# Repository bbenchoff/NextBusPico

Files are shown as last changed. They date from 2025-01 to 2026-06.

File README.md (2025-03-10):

# Multi-Stop Bus Tracker (and a tide display. and possibly weather.)

The render of the Bus Display

I live in SF, with some of the best public transit in the country. I would like to know when the next bus will be arriving at a stop near my house. Not just one stop, either: there are several bus lines that will all take me downtown, but they're all served by different stops. I need a device that will ping the city's API for _all_ the bus stops near my house, and condense that into a list I can put on a small display somewhere. I don't want to dedicate a whole computer to this task, so I need to build an embedded solution.

The standard MUNI bus display at some bus stops

This is somewhat different than the displays actually found at bus stops around the city (above). By their nature, the displays at one bus stop do not track the arrivals at other nearby bus stops. It can be done, I just need the data. This can be done through the [511.org API](https://511.org/). Given any bus stop in the city, this API will give me predicted times of arrivals each bus scheduled at that stop, its line number/letter, and its destination. There is a rate limit on this API of 60 requests per hour, but that only means I'm sending a request every 65 seconds.

But there are a few problems:

- The 511.org API *only* works with HTTPS. 
- The API *only* gives me gzipped JSON. I need to decompress this on the device.
- I need to do this on an embedded device. I'm using a Pi Pico2W, simply because that's the bullshit I'm currently on.

## Previous work and initial steps

I started this project with just a Raspberry Pi Pico (with Ethernet) simply as a proof of concept that it's possible to pull arrival data in an embedded device. [Some reddit user](https://www.reddit.com/r/sanfrancisco/comments/16x7zi4/made_a_next_muni_timer_with_a_few_other_handy/) built something similar with an ESP-32, but was confounded by the fact that 511.org only works with HTTPS, and the API only returns gzipped JSON. The solution for that project was to build a Node app to download and decompress the data. This is not an ideal solution.

There is [another project that does something like this](https://github.com/mmichon/esp-nextbus-mini/tree/master), using an ESP-8266. This project does not ping the 511.org API directly, but simply downloads data from [nextbus](http://nextbus.com/). Again, the two key problems are not addressed. This uses a second server, and doesn't interact with the 'ground truth' of the actual API data. Also the display on both of the above devices is really small.

The ideal solution should work even if there are only two computers left on the planet -- the 511.org server, and this device. This means solving the problems of getting data over HTTPS and decompressing the JSON file. I should also use a _good_ display for this, because I really hate how small those little I₂C displays are.

To solve these problems, I picked up a Pi Pico board with an Ethernet module tacked on. In my real job I've found this to be a great way to get data off a network, and the Pico should have more than enough RAM to store the decompressed JSON as well as a screenbuffer or two. The Pico with Ethernet board allowed me to move over to a PicoW board in the future, giving me WiFi connectivity. 

## Problem 1: HTTPS and Decompressing JSON

Getting data from the 511.org API presents two immediate challenges: the API requires HTTPS connections, and it only returns gzipped JSON data. This is an unusual requirement for embedded projects; most examples of accessing web APIs on microcontrollers use plain HTTP, and compressed data is rarely seen in embedded applications.

HTTPS was the easier of these problems to solve; the SSLClient library for Arduino handles the SSL/TLS handshake and encryption. The only tricky part was getting the correct SSL certificates in the right format. [A web-based tool](https://openslab-osu.github.io/bearssl-certificate-utility/) creates a trust_anchors.h file containing the certificates needed for SSL verification - you just input the domain name (api.511.org) and it generates the properly formatted certificate array that SSLClient needs. With the correct certificates in place, SSLClient manages the encrypted connection transparently.

Figuring out the payload was another matter entirely. At first, every response I was getting from the server was garbage, even when telling the server to send me *un*compressed JSON. Looking at the hex dump of the data I was receiving told me another story.

The key insight that told me it was gzipped JSON

### I can not tell you how many times looking at a hex dump has saved my ass.

The 0x1F 0x8B is the magic number for gzip encoding. Once I saw that, I knew I needed a library for decompressing gzip on an embedded platform. I found the [miniz library](https://github.com/richgel999/miniz), a portable library in C that handles the decompression. Even with this library, it's tricky; I need to skip past the 10-byte header, extract the uncompressed size from the last 4 bytes, and decompress everything in between. I also need to manage the memory correctly with malloc() and free(), and no I haven't learned Rust yet. 

## Problem 2: Organizing this data

The 511.org API gives me a lot of data for each bus stop - route numbers, destinations, arrival times, and current locations. But I need to track multiple stops at once, and merge all this information into something useful. This meant creating a data structure that could handle multiple stops and multiple arrivals at each stop.

The solution I came up with uses a simple array of stop data structures. Each stop structure contains its stop code (a unique identifier for each bus stop) and an array of upcoming arrivals. Each arrival contains the bus line number, destination, arrival time, and stop name. The size of these arrays is fixed - I can track up to 20 arrivals per stop, which is more than enough for my needs.

When new data comes in from the API, I clear out the old arrivals for that stop and fill in the new ones. There's also a cleanup function that removes arrivals that have already passed. The most interesting part is how the display function handles all this data - it looks through all stops and all arrivals, groups buses going to the same destination, and creates a consolidated list of arrival times. For example, if the 48 bus is coming to the same stop in 5, 20, and 35 minutes, it shows up as one line: "48 Inbound in 5, 20, 35 minutes". Pinging two stops means I can also get "28 to the Presidio in 2, 12, 23 minutes".

Getting the bus displays four bus stops around Market and Van Ness

The above is the device pinging four bus stops ({"15696", "15565", "13220", "15678"}) around Market and Van Ness. Each stop has several bus lines on it, and the code correctly displays the line, destination, and arrival time. This might seem like overkill for just checking bus times, but it means I can glance at the display and immediately see every bus that's coming to any stop near my house, sorted by arrival time.

## Problem 3: Let's add a display!

This thing needs a display, something low power, too. I settled on an ePaper display, the [Microtips MT-DEPG0750RWU790F30](https://www.mouser.com/ProductDetail/Microtips-Technology/MT-DEPG0750RWU790F30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), a 7.5" display with a resolution of 480x800. There are a few things that brought me to this display: it has an on-chip framebuffer, which can [vastly increase capabilities if you're smart](https://bbenchoff.github.io/pages/dumb.html), and programmable waveforms for the eInk. This is a display meant for price labels in a grocery store, so the refresh rate isn't great.

The breakout PCB for the e-paper panel

Schematic for the Epaper driver

I whipped up a board in KiCad that would support this board. The panel driver circuit is ripped straight from the datasheet and drives the panel with SPI. In addition to that, I added a few [solderable standoffs](https://www.digikey.com/en/products/detail/w%C3%BCrth-elektronik/9774060360R/4810237) and a power circuit built around TI's TPS560200, giving me 3.3V from 4.5V to 17V. There is a vertical USB-C (power only) on the board, because i envision this being something like a picture frame. There is also a ~12VDC power input ORed with the USB-C power input in case I ever want to install this inside a wall.

Writing the driver/library for the e-paper display proceeded as it usually does when I write a display driver -- tearing my hair out and somehow it magically works.

## E-Paper display pain points

This is not instructions on how to write a driver for an e-paper display. Instead, this is a log of what I found difficult. If you just want the code, it's somewhere over [in the github repo for this project](https://github.com/bbenchoff/nextBusPico).

### Pain Points and Displaying Images

This code uses a small subset of the [Adafruit GFX library](https://github.com/adafruit/Adafruit-GFX-Library) for housekeeping tasks such as rotation and loading a set image format into RAM. This also gives me a stock font so error messages can be displayed on the screen. However, the actual display needs a much more robust and aesthetically pleasing solution.

While standard bitmap fonts are good enough for the text, the bus routes themselves needed something _extra_. I created about seventy 180x180 pixel graphics for **all** of the bus and transit routes in SF. The design is Bahnschrift Bold, 175pt for the main letter/number, 24pt of supplementary text. Rail lines are in giant circles, cable cars are cute little cable cars, and the 39 Coit is Coit tower. I'm not happy with all of the route logos, but it's a start:

Bitmaps of all the bus route logos

I had a few pain points in developing this code, the first being what happens every time I write a display driver. Because I'm using this in a portrait orientation, the display was all cattywampus -- up was right, left was down, and at one point the display was mirrored in the vertical axis. This is a pain, but I just had to work through it.

The second pain point was the lack of a partial refresh for the display. The core function of this display means it doesn't change much. It's just a list of bus lines, their destinations, a stop point, and a list of minutes until the bus arrives. Obviously the arrival time changes every 60 seconds, but the rest of the display will usually only change late at night when the busses stop running or early in the morning. A partial refresh for just the arrival times is the way to go.

Unfortunately, the display I'm using for this project doesn't support partial refresh. I thought it did -- why wouldn't an e-paper display support partial refresh? The MT-DEPG0750RWU790F30 does not, however. But pinouts for 7.5" e-paper displays are all very similar, and I can use the same breakout board to test out other panels.

## An enclosure

The render of the Bus Display

The enclosure is a 3-piece ordeal. The legs bolt onto the back with heat-set inserts installed in the back. The PCB/EPD assembly mounts to the back of the display with the solderable standoffs installed on the PCB. The front is a snap-fit assembly, with the geometry shown in the sectional diagram below.

These parts were 3D printed on a Prusa Mk4 in carbon fiber-filled PC. I'm only building one of these, after all.

Front and back of the enclosure

sectional analysis of the enclosure

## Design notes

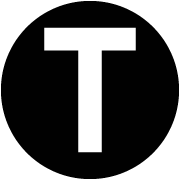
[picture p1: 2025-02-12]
Graphics/Transit_Graphics/T.png

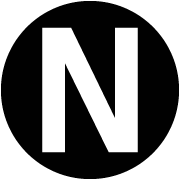
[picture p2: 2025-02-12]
Graphics/Transit_Graphics/N.png

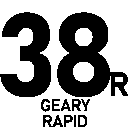
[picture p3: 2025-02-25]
Graphics/Transit_Graphics/arduino_output/38R_processed.png

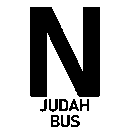
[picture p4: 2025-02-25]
Graphics/Transit_Graphics/arduino_output/NBUS_processed.png

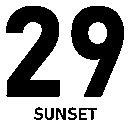
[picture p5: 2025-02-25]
Graphics/Transit_Graphics/arduino_output/29_processed.png

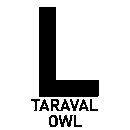
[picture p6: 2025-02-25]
Graphics/Transit_Graphics/arduino_output/LOWL_processed.png

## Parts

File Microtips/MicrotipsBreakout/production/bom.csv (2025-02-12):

Designator | Footprint | Quantity | Value | LCSC Part #
C1, C2, C3, C4, C5, C7, C8 | 1206 | 7 | 4.7uF
C10, C11, C12, C13, C16, C17 | CP_EIA-3528-12_Kemet-T | 6 | 10uF
C14, C15 | 1206 | 2 | 10uF
C6, C9 | 1206 | 2 | 1uF
D1, D2, D3 | D_SOD-123 | 3 | MBR0530
J1 | Jushuo_AFC07-S24FCA-00_1x24-1MP_P0.50_Horizontal | 1 | Conn_01x24_Pin
L1 | L_TDK_VLS6045EX_VLS6045AF | 1 | 10uH
L2 | L_Chilisin_BMRB00050518-B | 1 | L | C5349679
P1, P2, P3, P4 | 9774060360R | 4 | ~
Q1 | SOT-323_SC-70 | 1 | Si1308EDL
Q2, Q5 | SOT-23 | 2 | PNP | C5300004
Q3, Q4 | SOT-23 | 2 | PMOS | C347476
R1 | 0805 | 1 | 470mOhm
R2, R3 | 0603 | 2 | 5.1k | C23186
R4, R5, R6 | 0603 | 3 | 100k | C2906980
R7 | 0603 | 1 | 61.9k | C23091
R8 | 0603 | 1 | 20k | C4184
U1 | RPi_Pico_SMD_TH | 1 | Pico
U2 | TYPE-C-SMD_USB4120-03-C | 1 | TYPE-C 16PLT-H10.0
U3 | SOT-23-5 | 1 | TPS560200 | C83671

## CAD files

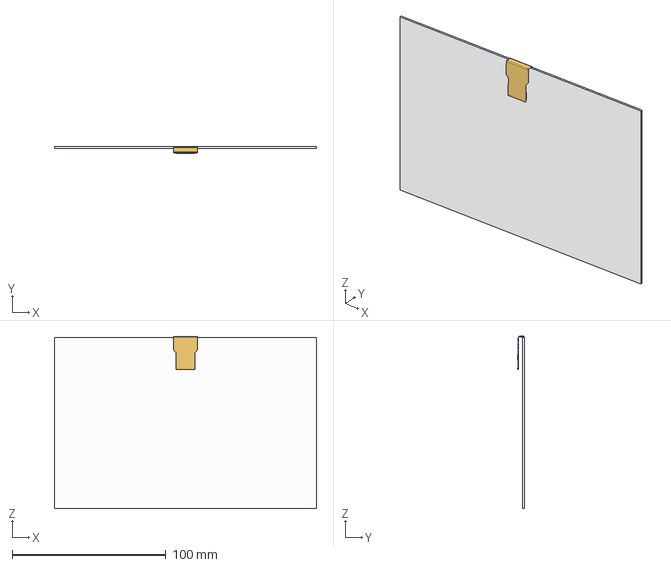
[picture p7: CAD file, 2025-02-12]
Microtips/MicrotipsBreakout/MT_DEPG0750RWU790F30 v1.step
170.2 x 4.27 x 111.8 mm

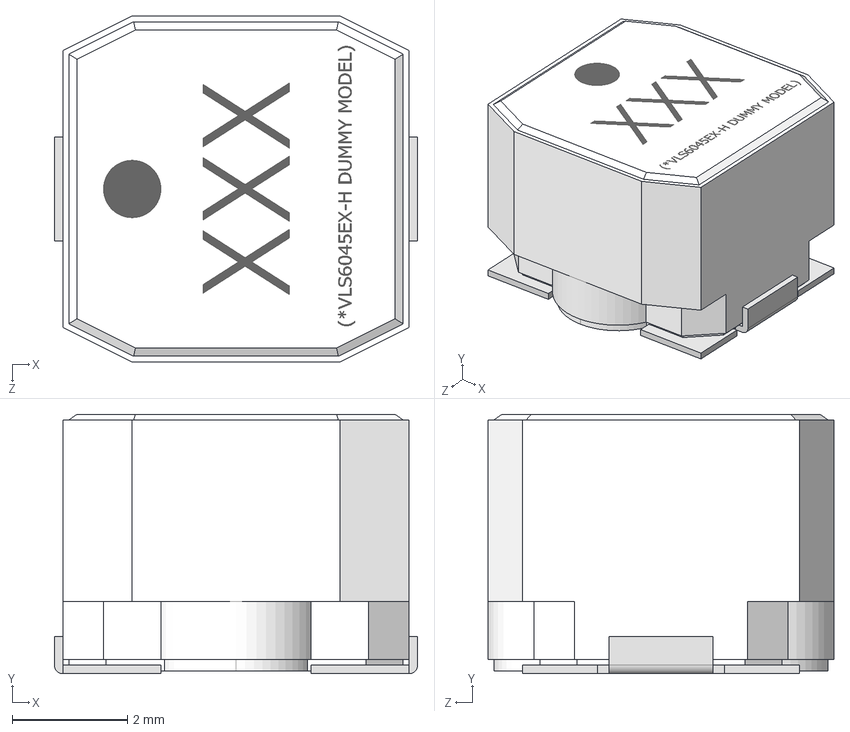
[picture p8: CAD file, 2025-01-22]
Microtips/MicrotipsBreakout/vls6045ex-h.step
6.30 x 4.50 x 6.00 mm
VLS6045EX-H_C(3Dmodel)
VLS6045EX-H_T(3Dmodel)

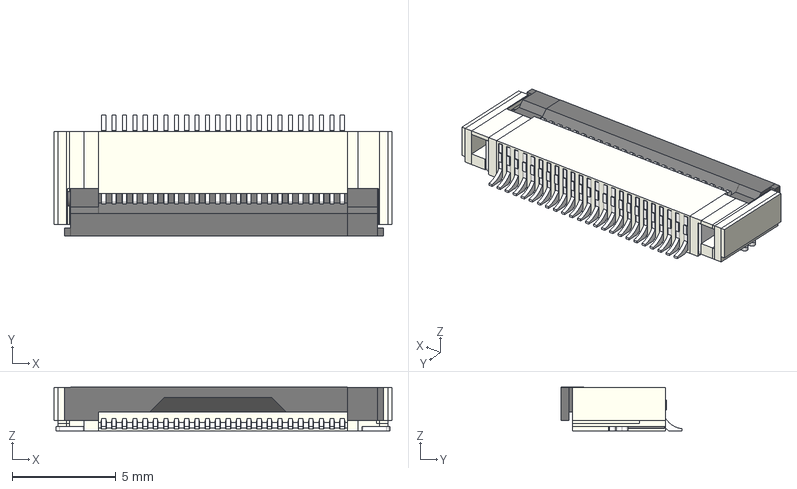
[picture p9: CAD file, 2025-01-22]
Microtips/MicrotipsBreakout/FPC-24.stp
16.3 x 5.85 x 2.11 mm

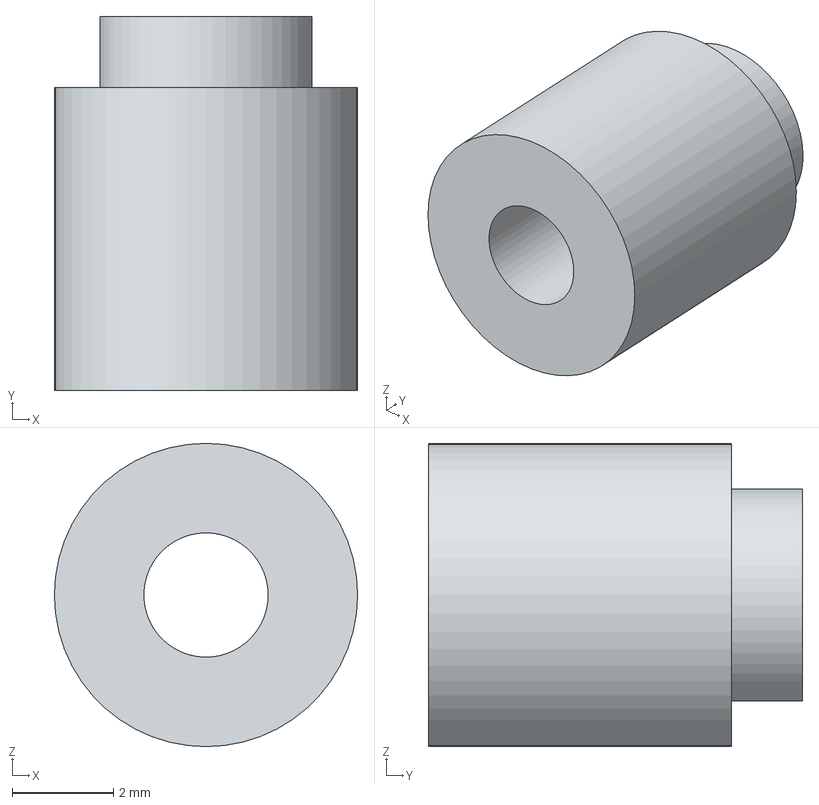
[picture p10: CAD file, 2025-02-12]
Microtips/MicrotipsBreakout/9774060360R (rev1).stp
6.00 x 7.40 x 6.00 mm

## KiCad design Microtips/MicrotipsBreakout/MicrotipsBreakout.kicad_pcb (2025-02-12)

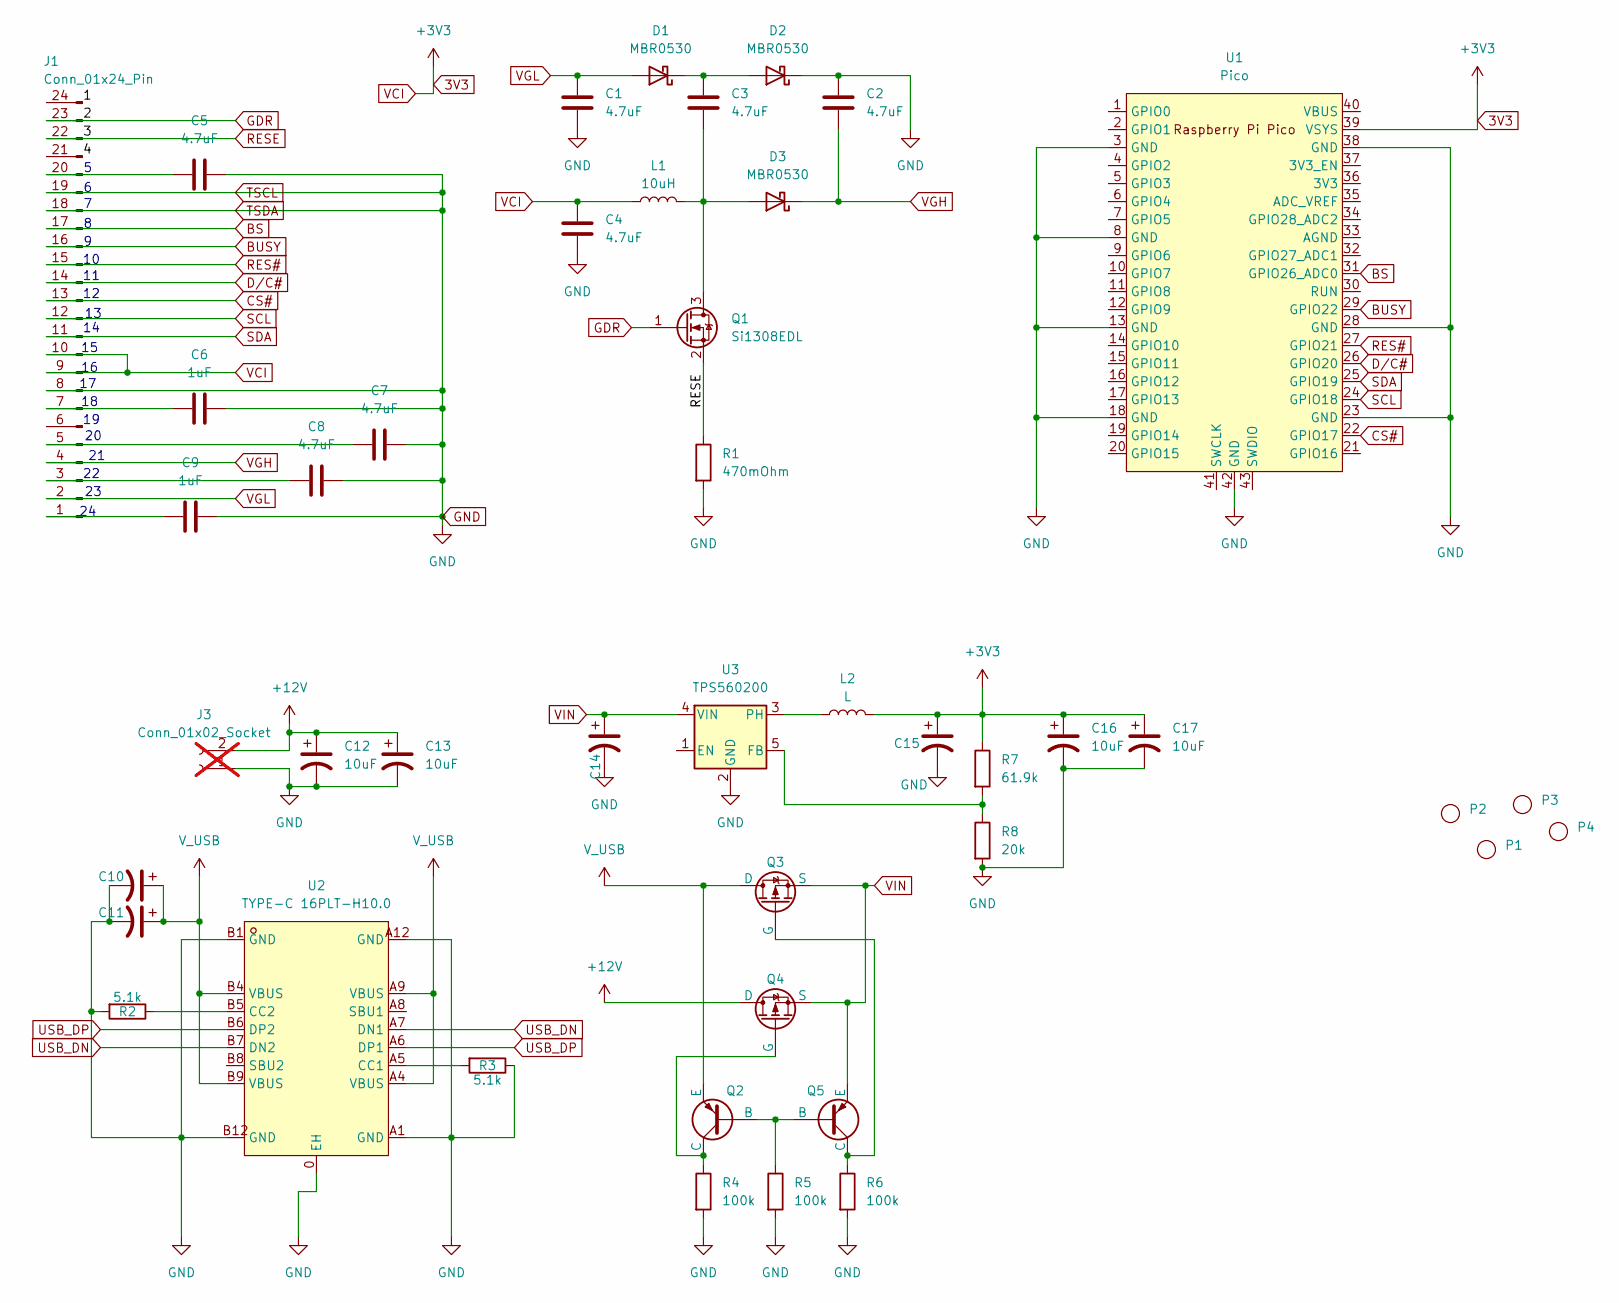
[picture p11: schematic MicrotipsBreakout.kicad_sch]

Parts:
C1, C2, C3, C4, C5, C7, C8: 4.7uF; C_1206_3216Metric; LCSC Part C132148
C6, C9: 1uF; C_1206_3216Metric; LCSC Part C28322
C10, C11, C12, C13, C16, C17: 10uF; CP_EIA-3528-12_Kemet-T; LCSC Part C7193
C14, C15: 10uF; C_1206_3216Metric; LCSC Part C14860
D1, D2, D3: MBR0530; D_SOD-123; LCSC Part C41383968
J1: Conn_01x24_Pin; Jushuo_AFC07-S24FCA-00_1x24-1MP_P0.50_Horizontal
J3: Conn_01x02_Socket; PinSocket_1x02_P2.54mm_Vertical; not fitted
L1: 10uH; L_TDK_VLS6045EX_VLS6045AF; LCSC Part C360734
L2: L; L_Chilisin_BMRB00050518-B; LCSC C5349679
P1, P2, P3, P4: 9774060360R
Q1: Si1308EDL; SOT-323_SC-70; LCSC Part C7603347
Q2, Q5: PNP; SOT-23; LCSC C5300004
Q3, Q4: PMOS; SOT-23; LCSC C347476
R1: 470mOhm; R_0805_2012Metric; LCSC Part C705493
R2, R3: 5.1k; R_0603_1608Metric; LCSC C23186
R4, R5, R6: 100k; R_0603_1608Metric; LCSC C2906980
R7: 61.9k; R_0603_1608Metric; LCSC C23091
R8: 20k; R_0603_1608Metric; LCSC C4184
U1: Pico; RPi_Pico_SMD_TH
U2: TYPE-C 16PLT-H10.0; TYPE-C-SMD_USB4120-03-C; LCSC Part C3151749
U3: TPS560200; SOT-23-5; LCSC C83671

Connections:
3V3: C4.1, C15.1, C16.1, C17.1, J1.9, J1.10, L1.1, L2.2, R7.1, U1.39 (VSYS)
+12V: C12.1, C13.1, J3.2, Q4.3 (D)
BS: J1.17, U1.31 (GPIO26_ADC0)
BUSY: J1.16, U1.29 (GPIO22)
CS#: J1.13, U1.22 (GPIO17)
D/C#: J1.14, U1.26 (GPIO20)
GDR: J1.23, Q1.1 (G)
GND: C1.2, C2.1, C4.2, C5.2, C6.2, C7.2, C8.2, C9.2, C10.2, C11.2, C12.2, C13.2, C14.2, C15.2, C16.2, C17.2, D2.1 (K), J1.8, J1.18, J1.19, J3.1, R1.2, R2.2, R3.1, R4.2, R5.2, R6.2, R8.2, U1.3 (GND), U1.8 (GND), U1.13 (GND), U1.18 (GND), U1.23 (GND), U1.28 (GND), U1.38 (GND), U1.42 (GND), U2.0 (EH), U2.A1 (GND), U2.A12 (GND), U2.B1 (GND), U2.B12 (GND), U3.2 (GND)
unnamed: C3.1, D1.1 (K), D2.2 (A)
unnamed: C3.2, D3.2 (A), L1.2, Q1.3 (D)
unnamed: C9.1, J1.1
unnamed: C8.1, J1.3
unnamed: C7.1, J1.5
unnamed: C6.1, J1.7
unnamed: C5.1, J1.20
unnamed: Q2.1 (B), Q5.1 (B), R5.1
unnamed: Q2.3 (C), Q4.1 (G), R4.1
unnamed: Q3.1 (G), Q5.3 (C), R6.1
unnamed: R3.2, U2.A5 (CC1)
unnamed: R2.1, U2.B5 (CC2)
unnamed: R7.2, R8.1, U3.5 (FB)
unnamed: L2.1, U3.3 (PH)
RES#: J1.15, U1.27 (GPIO21)
RESE: J1.22, Q1.2 (S), R1.1
SCL: J1.12, U1.24 (GPIO18)
SDA: J1.11, U1.25 (GPIO19)
USB_DN: U2.A7 (DN1), U2.B7 (DN2)
USB_DP: U2.A6 (DP1), U2.B6 (DP2)
VGH: C2.2, D3.1 (K), J1.4
VGL: C1.1, D1.2 (A), J1.2
VIN: C14.1, Q3.2 (S), Q4.2 (S), Q5.2 (E), U3.4 (VIN)
V_USB: C10.1, C11.1, Q2.2 (E), Q3.3 (D), U2.A4 (VBUS), U2.A9 (VBUS), U2.B4 (VBUS), U2.B9 (VBUS)

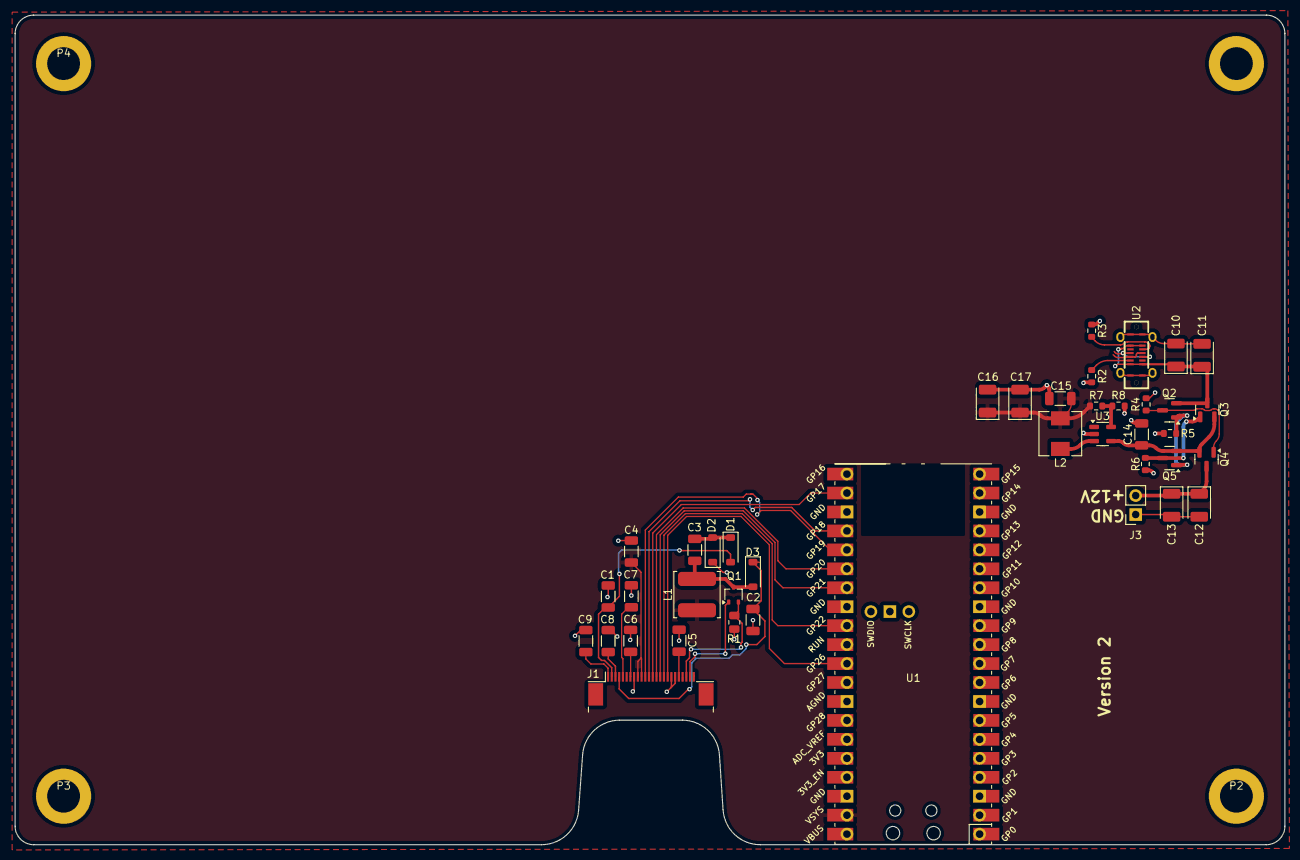
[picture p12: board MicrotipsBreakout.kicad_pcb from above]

Board: 2 copper layers, 170.2 x 111.2 mm, 44 parts (0 on the bottom side), 32 nets.

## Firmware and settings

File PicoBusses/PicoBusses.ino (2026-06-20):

/* This is a list of stop codes to gather. These are 
// Unique to _you_, and this should be the only thing
// you change. For example, if you want this device to 
// report on the stops at 9th Ave & Irving St (#17999),
// Lincoln Way & 9th Ave on bus 7 (#15301), and 9th &
// Lincoln Way for the 44 (#13220), this line would be:
//
//  String stopCodes[] = {"19777", "15301", "13220"};
//
// You can find the stop codes for your bus stop by
// looking at google maps and clicking on the bus stop
// you want to access with this device. Or look at your
// transit agency's website or something.
//
//  Using the actual cable car termini (stops "16063", 
//  "15063", "16644", "13860", and "13889") results in
//  times that are about 58 years in the future. Using
//  the next stop up from the cable car terminus (stops
//  "15081", "16068", "16645", "13855", and "13889")
//  gives you the actual time the next car will arrive.
//  This behavior correctly encodes something unique
//  about San Francisco. Locals do not wait in line at
//  the cable car termini. To board a cable car, you go
//  to the next stop up.
*/
String stopCodes[] = {"13565", "16633"};
//String stopCodes[] = {"15696", "15565", "13220", "15678"};  //Market and Van Ness
//String stopCodes[] = {"69925", "13211", "15300", "13220", "17999", "17996", "15301"}; //9th and Irving
//String stopCodes[] = {"15081", "16068", "16645", "13855", "13889"}; //One block up from each cable car termini
//String stopCodes[] = {"14114", "16061", "14105"}; // Cable Car and Coit demo
//String stopCodes[] = {"13124", "13144"}; // The two busiest stops, 3rd St & Folsom St and 3rd St & Bryant St
//String stopCodes[] = {"16006", "16007", "16921", "18099" }; // Demo at Bob's Donuts


// below is config.h; you will need to modify config.template.h
// and change the name of the file to config.h.
// config.h holds your wifi credentials and your 511.org API key.
#include "config.h"

// You should not have to adjust anything below this line.

//#define DEBUG_MODE

#include <SPI.h>
#include <WiFi.h>
#include <HTTPClient.h>

#include <SSLClient.h>
#include "trust_anchors.h"
#include "miniz.h"
#include <ArduinoUniqueID.h>
#include <NTPClient.h>
#include <TimeLib.h>
#include <ArduinoJson.h>
#include "imagedata.h"
#include "Globals.h"
#include "transit_bitmap.h"
#include "muni_bitmap.h"
#include "Fonts/FreeSansBold18pt7b.h"
#include "Fonts/FreeSansBold24pt7b.h"
#include "Fonts/FreeSans12pt7b.h"
#include <Adafruit_GFX.h>

#include "MT_EPD.h"

// Hardware watchdog (RP2040 / RP2350) — drives the display watchdog below.
#if defined(ARDUINO_ARCH_RP2040)
#include "hardware/watchdog.h"
#endif

#define COLORED     0
#define UNCOLORED   1

// Pin definitions
#define EPD_BS    26  // Bus Select
#define EPD_BUSY  22  // Busy signal
#define EPD_RST   21  // Reset
#define EPD_DC    20  // Data/Command
#define EPD_MOSI  19  // SPI MOSI
#define EPD_SCK   18  // SPI Clock
#define EPD_CS    17  // Chip Select

struct LineInfo {
  String lineRef;         // The line number/reference
  String destination;     // The destination 
  String stopPoint;       // The stop point
  bool active;            // Whether this line is active in current update
};

String CurrentTimeToString(time_t time);
time_t iso8601ToEpoch(String datetime);
MT_EPD display(EPD_CS, EPD_DC, EPD_RST, EPD_BUSY);

bool positionsInitialized = false;

// ---- Display watchdog -------------------------------------------------------
// The screen sometimes freezes for hours: a stuck e-paper BUSY line in
// waitUntilIdle(), a wedged TLS connect, or a dropped Wi-Fi that makes getData()
// fail forever while loop() keeps spinning. None of these reach updateDisplay(),
// so the panel never refreshes again.
//
// We arm the hardware watchdog once and feed it from petWatchdog(), which is
// sprinkled into every place core0 can block for a while (loop(), the WiFi
// connect loop, the getData() read/retry loops). petWatchdog() only feeds the
// dog while the screen has refreshed within DISPLAY_STALE_LIMIT_MS;
// lastDisplayUpdate == 0 keeps us fed through boot. If frames stop coming, the
// pets stop and the chip resets within WDT_TIMEOUT_MS, rerunning setup().
//
// (Earlier versions fed the dog from core1 and then from a timer IRQ. Both were
// flaky on the Pico 2 W: the CYW43 WiFi driver pauses core1 via multicore
// lockout, and the IRQ feeder didn't reliably fire during boot. Plain inline
// pets from core0 always run, so this is the dependable approach.)
//
// Set USE_DISPLAY_WATCHDOG to 0 to compile the watchdog out entirely.
#define USE_DISPLAY_WATCHDOG 1

const unsigned long DISPLAY_STALE_LIMIT_MS = 5UL * 60UL * 1000UL; // ~5 minutes
const uint32_t WDT_TIMEOUT_MS = 12000;  // > worst-case blocking op (TLS connect); within RP2350 limit
volatile unsigned long lastDisplayUpdate = 0; // millis() of last display.display()

// Feed the watchdog, but only while the screen is still refreshing (or we're in
// the boot grace window). Safe to call anywhere; compiles to nothing when off.
inline void petWatchdog() {
#if defined(ARDUINO_ARCH_RP2040) && USE_DISPLAY_WATCHDOG
  if ((millis() - lastDisplayUpdate) < DISPLAY_STALE_LIMIT_MS) {
    watchdog_update();
  }
#endif
}

// Arm the hardware watchdog. Called once, early in setup().
inline void startDisplayWatchdog() {
#if defined(ARDUINO_ARCH_RP2040) && USE_DISPLAY_WATCHDOG
  watchdog_enable(WDT_TIMEOUT_MS, true);
  watchdog_update();
#endif
}

LineInfo lineInfoArray[10];
int lineInfoCount = 0;

const int ROW_HEIGHT = 135;


void printHexBuffer(const uint8_t* buffer, size_t length);
void getData(void);
void decompressGzippedData(const uint8_t *gzippedData, size_t gzippedDataSize);
uint32_t getUncompressedLength(const uint8_t* data, size_t dataSize);
void parseAndFormatBusArrivals(const String& jsonData);
void removeOldArrivals(void);
void displayArrivals(void);
void resetDevice(void);
bool connectToWiFiWithTimeout(void);
void collectActiveLines(void);
void updateDisplay(void);
const uint8_t* getTransitLogo(String lineRef);


void setup() {
  Serial.begin(115200);
  delay(1000);
  Serial.println("EPD image test");
  Serial.println(">>> BUILD CHECK: inline-watchdog + immediate-fetch (rev C) <<<");

  // Arm the watchdog up front. lastDisplayUpdate is still 0, so petWatchdog()
  // stays in its boot grace window until the first real frame sets the clock.
  startDisplayWatchdog();

  // Configure pins
  pinMode(EPD_BS, OUTPUT);
  pinMode(EPD_CS, OUTPUT);
  pinMode(EPD_DC, OUTPUT);
  pinMode(EPD_RST, OUTPUT);
  pinMode(EPD_BUSY, INPUT);
  
  digitalWrite(EPD_BS, LOW);
  digitalWrite(EPD_CS, HIGH);
  digitalWrite(EPD_DC, HIGH);
  digitalWrite(EPD_RST, HIGH);
  
  SPI.setSCK(EPD_SCK);
  SPI.setTX(EPD_MOSI);
  SPI.begin();
  SPI.beginTransaction(SPISettings(4000000, MSBFIRST, SPI_MODE0));
  
  // Initialize display
  display.begin();
  display.setRotation(1);
  display.clearDisplay();
  
  // Draw the bitmap at position (0,0)
  /* Keeping this here for later, these are the 'rows'
  display.drawBitmap(0, 0, transit_logo_48, 130, 130, MT_EPD::EPD_BLACK);
  display.drawBitmap(0, 135, transit_logo_L, 130, 130, MT_EPD::EPD_BLACK);
  display.drawBitmap(0, 270, transit_logo_LOWL, 130, 130, MT_EPD::EPD_BLACK);
  display.drawBitmap(0, 405, transit_logo_CA, 130, 130, MT_EPD::EPD_BLACK);
  display.drawBitmap(0, 540, transit_logo_714, 130, 130, MT_EPD::EPD_BLACK);
  display.drawBitmap(0, 675, transit_logo_39T, 130, 130, MT_EPD::EPD_BLACK);
  

  display.drawBitmap(0, 0, transit_logo_48, 130, 130, MT_EPD::EPD_BLACK);

  display.setFont(&FreeSans12pt7b);
  display.setCursor(135, 25);
  display.setTextColor(MT_EPD::EPD_BLACK);
  display.println("To 22nd St + Iowa St");

  display.setFont(&FreeSans12pt7b);
  display.setCursor(135, 60);
  display.setTextColor(MT_EPD::EPD_BLACK);
  display.println("From 39th Ave & Rivera St");

  // Test the FreeSansBold24pt7b font
  display.setFont(&FreeSansBold24pt7b);
  display.setCursor(150, 115);
  display.setTextColor(MT_EPD::EPD_BLACK);
  display.println("20, 120, 180");
  */

  display.drawBitmap(0, 250, epd_bitmap_Muni_worm_logo, 480, 258, MT_EPD::EPD_RED);

  
  // Do ONE full update with both logo and initial text
  display.display();
  lastDisplayUpdate = millis();  // first real frame: anchors the watchdog's stale clock
  petWatchdog();
  // waitUntilIdle() already blocked until the panel finished; a short settle is plenty
  delay(1000);

  // Connect to WiFi with timeout
  if (!connectToWiFiWithTimeout()) {
    resetDevice(); // Loop back to the beginning, we're fucked.
  }

  // Figure out the stop codes for all this shit
  for (int i = 0; i < sizeof(stopCodes)/sizeof(stopCodes[0]); i++) {
    stopCodeDataArray[i].stopCode = stopCodes[i];
    stopCodeDataArray[i].arrivalCount = 0; // Initialize the count of arrivals to 0
  }

  Serial.println("finished setup");

}
  
void loop() {
  petWatchdog();  // feed the watchdog whenever the screen is healthy

  static bool firstFetch = true;          // fetch right away on boot, don't wait 65 s
  unsigned long currentMillis = millis(); // capture the current time

  if (firstFetch || (currentMillis - previousMillis >= interval)) { // first run, or 65 s elapsed
    firstFetch = false;
    previousMillis = currentMillis;

    Serial.print("Fetching stopCode ");
    Serial.println(stopCodeDataArray[currentStopCodeIndex].stopCode);
    getData(stopCodeDataArray[currentStopCodeIndex].stopCode);
    #ifdef DEBUG_MODE
    Serial.println(CurrentTimeToString(currentTime));
    #endif
    removeOldArrivals();

    Serial.print("Data length: ");
    Serial.println(globalUncompressedDataStr.length());

    if (globalUncompressedDataStr.length() > 0) {
        #ifdef DEBUG_MODE
        Serial.print("JSON string length: ");
        Serial.println(globalUncompressedDataStr.length());
        #endif
        parseAndFormatBusArrivals(globalUncompressedDataStr);
        displayArrivals();
        currentStopCodeIndex = (currentStopCodeIndex + 1) % (sizeof(stopCodes)/sizeof(stopCodes[0]));
        updateDisplay();
    } else {
        Serial.println("No data or failed to fetch data");
    }
    Serial.println("");
    Serial.println("");
  }
}

// (watchdog feeder lives up top now — see petWatchdog() / startDisplayWatchdog())

void resetDevice() {
  // On occasion of the WiFi not working, need to tell the user.
  display.begin();
  display.setCursor(20, 490);
  display.setTextSize(2);
  display.setTextColor(0x0000);
  display.println("WiFi Not Connected!");
  display.setCursor(20, 510);
  display.println("Check WiFi credentials");
  display.setCursor(20, 530);
  display.println("Resetting...");
  display.display();
  lastDisplayUpdate = millis();  // keep the watchdog from rebooting us before the message is read

  // Give the user time to read the message, feeding the dog so it doesn't cut this short
  for (int i = 0; i < 60; i++) {
    petWatchdog();
    delay(1000);
  }

  // Reset the Pico
  #if defined(ARDUINO_ARCH_RP2040)
    watchdog_enable(1, 1);  // 1ms timeout; the while(1) below never pets, so we reboot
    while(1);  // Wait for watchdog to reset
  #else
    NVIC_SystemReset();  // System reset
  #endif
}

bool connectToWiFiWithTimeout() {
  Serial.print("Connecting to WiFi");
  
  WiFi.mode(WIFI_STA);
  WiFi.begin(ssid, password);
  
  // Try to connect for 3 minutes (180 seconds)
  const unsigned long timeout = 180000; // 3 minutes in milliseconds
  unsigned long startTime = millis();
  
  while (WiFi.status() != WL_CONNECTED) {
    petWatchdog();
    // Check if timed out
    if (millis() - startTime > timeout) {
      Serial.println("\nWiFi connection timed out after 3 minutes!");
      return false;
    }
    
    delay(500);
    Serial.print(".");
  }
  
  Serial.println("\nConnected to WiFi!");
  Serial.print("IP address: ");
  Serial.println(WiFi.localIP());
  
  return true;
}

String CurrentTimeToString(time_t time) {
    char timeString[20];

    snprintf(timeString, sizeof(timeString), "%04d-%02d-%02d %02d:%02d:%02d", 
             year(time), month(time), day(time), hour(time), minute(time));

    return String(timeString);
}

time_t iso8601ToEpoch(String datetime) {
    tmElements_t tm;

    int Year, Month, Day, Hour, Minute, Second;
    sscanf(datetime.c_str(), "%d-%d-%dT%d:%d:%dZ", &Year, &Month, &Day, &Hour, &Minute, &Second);

    tm.Year = Year - 1970; // tmElements_t.Year is the number of years since 1970
    tm.Month = Month;
    tm.Day = Day;
    tm.Hour = Hour;
    tm.Minute = Minute;
    tm.Second = Second;

    return makeTime(tm);
}


void printHexBuffer(const uint8_t* buffer, size_t length) {
  for (size_t i = 0; i < length; i++) {
    if (buffer[i] < 0x10) {
      Serial.print("0"); // Add leading zero for values < 0x10
    }
    Serial.print(buffer[i], HEX);
    Serial.print(" ");
    if ((i + 1) % 16 == 0) { // Line break every 16 bytes
      Serial.println();
    }
  }
  Serial.println(); // Final newline
}

void getData(String stopCode) {
  const int maxRetries = 3;
  int retryCount = 0;
  bool requestSuccess = false;

  #ifdef DEBUG_MODE
  Serial.println("Got to getData");
  Serial.println("Attempting to connect to server...");
  #endif

  while (!requestSuccess && retryCount < maxRetries) {
    petWatchdog();
    // Make sure we start with a fresh connection
    client.stop();
    delay(100);  // Give it a moment to clean up

    #ifdef DEBUG_MODE
    Serial.print("Connecting to: ");
    Serial.print(server);
    Serial.println(":443");
    #endif

    if (!client.connect(server, 443)) {
      Serial.println("Connection failed! Check server name, WiFi, or SSL.");
      retryCount++;
      delay(1000);
      continue;
    }

    #ifdef DEBUG_MODE
    Serial.println("Connected to server! Sending request...");
    #endif

    String path = "/transit/StopMonitoring?api_key=" + 
                 APIkey + "&agency=SF&stopCode=" + stopCode + "&format=json";

    // Send HTTP request
    String request = "GET " + path + " HTTP/1.1\r\n";
    request += "Host: " + String(server) + "\r\n";
    request += "User-Agent: " + User_Agent + "\r\n";
    request += "Connection: close\r\n\r\n";
    
    // Send the complete request at once
    client.print(request);

    // Wait a bit for the response to start coming in
    delay(100);

    // Read the response while the connection is alive
    String response = "";
    unsigned long timeout = millis();
    
    while (client.connected() && (millis() - timeout < 5000)) {
      petWatchdog();
      while (client.available()) {
        char c = client.read();
        response += c;
        timeout = millis();  // Reset timeout when we receive data
      }
    }

    // Clean up the connection
    client.stop();

    if (response.length() > 0) {
      #ifdef DEBUG_MODE
      Serial.println("\nResponse received:");
      Serial.println(response);
      #endif
      // Look for the end of headers (double newline)
      int bodyStart = response.indexOf("\r\n\r\n");
      if (bodyStart > 0) {
        String body = response.substring(bodyStart + 4);
        #ifdef DEBUG_MODE
        Serial.println("\nBody length: " + String(body.length()));
        #endif
        // Convert to bytes for decompression
        size_t bodyLen = body.length();
        uint8_t* bodyBytes = (uint8_t*)malloc(bodyLen);
        if (bodyBytes != nullptr) {
          memcpy(bodyBytes, body.c_str(), bodyLen);
          #ifdef DEBUG_MODE
          printHexBuffer(bodyBytes, bodyLen);  // Print hex values
          #endif
          decompressGzippedData(bodyBytes, (size_t)bodyLen);  // Explicitly cast to size_t
          free(bodyBytes);
          requestSuccess = true;
        } else {
          #ifdef DEBUG_MODE
          Serial.println("Failed to allocate memory for body");
          #endif
        }
      }
    } else {
      #ifdef DEBUG_MODE
      Serial.println("No response received");
      #endif
      retryCount++;
    }
  }

  if (!requestSuccess) {

    #ifdef DEBUG_MODE
    Serial.println("Failed to get data after all retries");
    #endif
    globalUncompressedDataStr = "";
  }
}

void decompressGzippedData(const uint8_t *gzippedData, size_t gzippedDataSize) {
  #ifdef DEBUG_MODE
  Serial.print("Attempting to decompress data of size: ");
  Serial.println(gzippedDataSize);
  #endif

  // Find the start of the gzip data by looking for the gzip magic numbers
  size_t dataStart = 0;
  for (size_t i = 0; i < gzippedDataSize - 1; i++) {
    if (gzippedData[i] == 0x1F && gzippedData[i + 1] == 0x8B) {
      dataStart = i;
      break;
    }
  }

  // Get the actual gzipped data size
  size_t actualGzipSize = gzippedDataSize - dataStart;
  
  // Use the getUncompressedLength function to determine the expected uncompressed size
  uint32_t expectedUncompressedSize = getUncompressedLength(gzippedData + dataStart, actualGzipSize);
  
  if (expectedUncompressedSize == 0) {
    #ifdef DEBUG_MODE
    Serial.println("Invalid gzip data or couldn't determine uncompressed size");
    #endif
    return;
  }

  uint8_t *uncompressedData = (uint8_t *)malloc(expectedUncompressedSize);
  if (uncompressedData == NULL) {
    #ifdef DEBUG_MODE
    Serial.println("Failed to allocate memory for decompression.");
    #endif
    return;
  }

  // The gzip header is usually 10 bytes
  const size_t gzipHeaderSize = 10;
  const uint8_t *deflateData = gzippedData + dataStart + gzipHeaderSize;
  size_t deflateDataSize = actualGzipSize - gzipHeaderSize - 8; // Subtract 8 bytes for the gzip footer

  mz_ulong outBytes = expectedUncompressedSize;
  int status = tinfl_decompress_mem_to_mem(uncompressedData, outBytes, deflateData, deflateDataSize, 0);

  if (status == TINFL_DECOMPRESS_MEM_TO_MEM_FAILED) {
    #ifdef DEBUG_MODE
    Serial.println("Decompression failed.");
    #endif
  } 
  else {
    #ifdef DEBUG_MODE
    Serial.println("Decompression successful.");
    #endif
    globalUncompressedDataStr = "";

    // Convert uncompressed data to String
    for (size_t i = 0; i < outBytes; ++i) {
      globalUncompressedDataStr += (char)uncompressedData[i];
    }
    #ifdef DEBUG_MODE
    Serial.println("Decompressed data:");
    Serial.println(globalUncompressedDataStr);
    #endif


  }
  free(uncompressedData);
}


uint32_t getUncompressedLength(const uint8_t* data, size_t dataSize) {
    if (dataSize < 4) return 0; // this isn't right, bail.

    // The uncompressed size is stored in the last 4 bytes
    // of the gzip stream in little-endian format
    uint32_t uncompressedSize = data[dataSize - 4]
        | (data[dataSize - 3] << 8)
        | (data[dataSize - 2] << 16)
        | (data[dataSize - 1] << 24);

    return uncompressedSize;
}

void parseAndFormatBusArrivals(const String& jsonData) {
  // Clear existing data for the current stop code
  stopCodeDataArray[currentStopCodeIndex].arrivalCount = 0;

  // The first characters I'm getting are 0xEF 0xBB 0xBF, a byte order mark.
  //I need to delete those before deserializing.
  String cleanJsonData = jsonData.substring(3); 

  DynamicJsonDocument doc(40000);

  DeserializationError error = deserializeJson(doc, cleanJsonData);

  if (error) {
    #ifdef DEBUG_MODE
    Serial.print(F("deserializeJson() failed: "));
    Serial.println(error.f_str());
    #endif
    return;
  }

  // Extract the ResponseTimestamp from the JSON data
  const char* responseTimestamp = doc["ServiceDelivery"]["ResponseTimestamp"];
  if (responseTimestamp) {
      // Convert ISO8601 to epoch
      time_t serverTime = iso8601ToEpoch(String(responseTimestamp));

      //Serial.print(F("Server Time (epoch): "));
      //Serial.println(serverTime);

      setTime(serverTime);
      currentTime = serverTime;
  }

  JsonArray arr = doc["ServiceDelivery"]["StopMonitoringDelivery"]["MonitoredStopVisit"];
    int count = 0;
    for(JsonObject obj : arr) {
        if (count >= MAX_ARRIVALS) break; // Prevent overflow of arrivals array

        String lineRef = obj["MonitoredVehicleJourney"]["LineRef"].as<String>();
        String expectedArrivalTimeStr = obj["MonitoredVehicleJourney"]["MonitoredCall"]["ExpectedArrivalTime"].as<String>();
        String destinationDisplay = obj["MonitoredVehicleJourney"]["MonitoredCall"]["DestinationDisplay"].as<String>();
        String stopPointName = obj["MonitoredVehicleJourney"]["MonitoredCall"]["StopPointName"].as<String>();

        // Store the arrival data
        BusArrival& arrival = stopCodeDataArray[currentStopCodeIndex].arrivals[count];
        arrival.lineRef = lineRef;
        arrival.expectedArrivalTimeStr = expectedArrivalTimeStr;
        arrival.destinationDisplay = destinationDisplay;
        arrival.stopPointName = stopPointName;

        count++;
    }
    // Update the count of arrivals for the current stop code
    stopCodeDataArray[currentStopCodeIndex].arrivalCount = count;
}

void removeOldArrivals() {
    int i = 0;
    while (i < arrivalCount) {
        time_t expectedArrivalEpoch = iso8601ToEpoch(arrivals[i].expectedArrivalTimeStr);
        if (expectedArrivalEpoch <= now()) {
            // Shift all subsequent arrivals one position to the left
            for (int j = i; j < arrivalCount - 1; j++) {
                arrivals[j] = arrivals[j + 1];
            }
            arrivalCount--; // Decrease the count of arrivals
        } else {
            i++; // Only increase if if we didn't remove an arrival
        }
    }
}
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

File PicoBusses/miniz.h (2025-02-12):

#ifndef MINIZ_EXPORT
#define MINIZ_EXPORT
#endif


#define MINIZ_NO_TIME

/* miniz.c 3.0.0 - public domain deflate/inflate, zlib-subset, ZIP reading/writing/appending, PNG writing
   See "unlicense" statement at the end of this file.
   Rich Geldreich <richgel99@gmail.com>, last updated Oct. 13, 2013
   Implements RFC 1950: http://www.ietf.org/rfc/rfc1950.txt and RFC 1951: http://www.ietf.org/rfc/rfc1951.txt

   Most API's defined in miniz.c are optional. For example, to disable the archive related functions just define
   MINIZ_NO_ARCHIVE_APIS, or to get rid of all stdio usage define MINIZ_NO_STDIO (see the list below for more macros).

   * Low-level Deflate/Inflate implementation notes:

     Compression: Use the "tdefl" API's. The compressor supports raw, static, and dynamic blocks, lazy or
     greedy parsing, match length filtering, RLE-only, and Huffman-only streams. It performs and compresses
     approximately as well as zlib.

     Decompression: Use the "tinfl" API's. The entire decompressor is implemented as a single function
     coroutine: see tinfl_decompress(). It supports decompression into a 32KB (or larger power of 2) wrapping buffer, or into a memory
     block large enough to hold the entire file.

     The low-level tdefl/tinfl API's do not make any use of dynamic memory allocation.

   * zlib-style API notes:

     miniz.c implements a fairly large subset of zlib. There's enough functionality present for it to be a drop-in
     zlib replacement in many apps:
        The z_stream struct, optional memory allocation callbacks
        deflateInit/deflateInit2/deflate/deflateReset/deflateEnd/deflateBound
        inflateInit/inflateInit2/inflate/inflateReset/inflateEnd
        compress, compress2, compressBound, uncompress
        CRC-32, Adler-32 - Using modern, minimal code size, CPU cache friendly routines.
        Supports raw deflate streams or standard zlib streams with adler-32 checking.

     Limitations:
      The callback API's are not implemented yet. No support for gzip headers or zlib static dictionaries.
      I've tried to closely emulate zlib's various flavors of stream flushing and return status codes, but
      there are no guarantees that miniz.c pulls this off perfectly.

   * PNG writing: See the tdefl_write_image_to_png_file_in_memory() function, originally written by
     Alex Evans. Supports 1-4 bytes/pixel images.

   * ZIP archive API notes:

     The ZIP archive API's where designed with simplicity and efficiency in mind, with just enough abstraction to
     get the job done with minimal fuss. There are simple API's to retrieve file information, read files from
     existing archives, create new archives, append new files to existing archives, or clone archive data from
     one archive to another. It supports archives located in memory or the heap, on disk (using stdio.h),
     or you can specify custom file read/write callbacks.

     - Archive reading: Just call this function to read a single file from a disk archive:

      void *mz_zip_extract_archive_file_to_heap(const char *pZip_filename, const char *pArchive_name,
        size_t *pSize, mz_uint zip_flags);

     For more complex cases, use the "mz_zip_reader" functions. Upon opening an archive, the entire central
     directory is located and read as-is into memory, and subsequent file access only occurs when reading individual files.

     - Archives file scanning: The simple way is to use this function to scan a loaded archive for a specific file:

     int mz_zip_reader_locate_file(mz_zip_archive *pZip, const char *pName, const char *pComment, mz_uint flags);

     The locate operation can optionally check file comments too, which (as one example) can be used to identify
     multiple versions of the same file in an archive. This function uses a simple linear search through the central
     directory, so it's not very fast.

     Alternately, you can iterate through all the files in an archive (using mz_zip_reader_get_num_files()) and
     retrieve detailed info on each file by calling mz_zip_reader_file_stat().

     - Archive creation: Use the "mz_zip_writer" functions. The ZIP writer immediately writes compressed file data
     to disk and builds an exact image of the central directory in memory. The central directory image is written
     all at once at the end of the archive file when the archive is finalized.

     The archive writer can optionally align each file's local header and file data to any power of 2 alignment,
     which can be useful when the archive will be read from optical media. Also, the writer supports placing
     arbitrary data blobs at the very beginning of ZIP archives. Archives written using either feature are still
     readable by any ZIP tool.

     - Archive appending: The simple way to add a single file to an archive is to call this function:

      mz_bool mz_zip_add_mem_to_archive_file_in_place(const char *pZip_filename, const char *pArchive_name,
        const void *pBuf, size_t buf_size, const void *pComment, mz_uint16 comment_size, mz_uint level_and_flags);

     The archive will be created if it doesn't already exist, otherwise it'll be appended to.
     Note the appending is done in-place and is not an atomic operation, so if something goes wrong
     during the operation it's possible the archive could be left without a central directory (although the local
     file headers and file data will be fine, so the archive will be recoverable).

     For more complex archive modification scenarios:
     1. The safest way is to use a mz_zip_reader to read the existing archive, cloning only those bits you want to
     preserve into a new archive using using the mz_zip_writer_add_from_zip_reader() function (which compiles the
     compressed file data as-is). When you're done, delete the old archive and rename the newly written archive, and
     you're done. This is safe but requires a bunch of temporary disk space or heap memory.

     2. Or, you can convert an mz_zip_reader in-place to an mz_zip_writer using mz_zip_writer_init_from_reader(),
     append new files as needed, then finalize the archive which will write an updated central directory to the
     original archive. (This is basically what mz_zip_add_mem_to_archive_file_in_place() does.) There's a
     possibility that the archive's central directory could be lost with this method if anything goes wrong, though.

     - ZIP archive support limitations:
     No spanning support. Extraction functions can only handle unencrypted, stored or deflated files.
     Requires streams capable of seeking.

   * This is a header file library, like stb_image.c. To get only a header file, either cut and paste the
     below header, or create miniz.h, #define MINIZ_HEADER_FILE_ONLY, and then include miniz.c from it.
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

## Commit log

2024-02-02 adding arduino hardware
2024-02-05 Getting the time and correctly parsing the json strings
    [PicoBusses.ino]
2024-02-22 pico update
2024-02-24 change SPI implementation
2025-01-22 Start on the microtips PCB
    [MicrotipsBreakout.kicad_pcb, MicrotipsBreakout.kicad_sch]
2025-01-23 Added Pico
    [MicrotipsBreakout.kicad_pcb, MicrotipsBreakout.kicad_sch]
2025-02-12 made graphics; building EPD driver
    [9774060360R (rev1).stp, MT_DEPG0750RWU790F30 v1.step, MicrotipsBreakout.kicad_pcb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]
2026-06-20 Bulletproofed the thing -- no longer stalls, WTD
    [PicoBusses.ino]
